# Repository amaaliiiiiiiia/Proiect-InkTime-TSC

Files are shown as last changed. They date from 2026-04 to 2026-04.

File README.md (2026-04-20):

# Proiect-InkTime-TSC
### Diagrama Bloc
Diagrama_bloc

## Tabel BOM (Bill of Materials)

| Componenta | Referinta | Link | Datasheet |
| :--- | :---: | :--- | :--- |
| **nRF52840-QFAA-F-R7** | `U1` | [JLC Parts](https://jlcpcb.com/partdetail/NordicSemicon-NRF52840_QFAA_FR7/C3606653) | [Datasheet](https://octopart.com/datasheet/nordic-semiconductor/NRF52840-QFAA-F-R7) |
| **MAX17048G+T10** | `U3` | [JLC Parts](https://jlcpcb.com/partdetail/2777647-MAX17048GT10/C2682616) | [Datasheet](https://www.analog.com/media/en/technical-documentation/data-sheets/MAX17048-MAX17049.pdf) |
| **BQ25180YBGR** | `IC1` | [JLC Parts](https://jlcpcb.com/partdetail/TexasInstruments-BQ25180YBGR/C3682423) | [Datasheet](https://www.alldatasheet.com/datasheet-pdf/view/1359210/TI/BQ25180YBGR.html) |
| **RT6160AWSC** | `IC2` | [JLC Parts](https://jlcpcb.com/partdetail/RichtekTech-RT6160AWSC/C7065276) | [Datasheet](https://www.alldatasheet.com/datasheet-pdf/view/1709403/RICHTEK/RT6160AWSC.html) |
| **BMA423** | `IC3` | [JLC Parts](https://jlcpcb.com/partdetail/BoschSensortec-BMA423/C189517) | [Datasheet](https://watchy.sqfmi.com/assets/files/BST-BMA423-DS000-1509600-950150f51058597a6234dd3eaafbb1f0.pdf) |
| **DRV2605YZFR** | `IC4` | [JLC Parts](https://jlcpcb.com/partdetail/TexasInstruments-DRV2605YZFR/C81079) | [Datasheet](https://www.ti.com/lit/ds/symlink/drv2605.pdf) |
| **2450AT18B100E** | `ANT1` | [JLC Parts](https://jlcpcb.com/partdetail/JohansonDielectrics-2450AT18B100E/C2917717) | [Datasheet](https://www.johansontechnology.com/datasheets/2450AT18B100/2450AT18B100.pdf) |
| **NX2016SA-32MHZ** | `X1` | [JLC Parts](https://jlcpcb.com/partdetail/NDK-NX2016SA_32MHZ_EXS00ACS06654/C5441424) | [Datasheet](https://mm.digikey.com/Volume0/opasdata/d220001/medias/docus/6749/CS11213-32M.pdf) |
| **ABS07-32.768KHZ** | `X2` | [JLC Parts](https://jlcpcb.com/partdetail/AbraconLLC-ABS07_32_768KHZT/C130253) | [Datasheet](https://abracon.com/Resonators/ABS07.pdf) |
| **ATFC-0201-1N0-B-T** | `L1, L2, L3` | [JLC Parts](https://jlcpcb.com/partdetail/AbraconLLC-ATFC_0201_1N0BT/C2042148) | [Datasheet](https://www.alldatasheet.com/datasheet-pdf/view/244743/ABRACON/ATFC-0201-1N0-BT.html) |
| **744043680** | `L5` | [JLC Parts](https://jlcpcb.com/partdetail/WurthElektronik-744043680/C2045671) | [Datasheet](https://www.we-online.com/catalog/datasheet/744043680.pdf) |
| **MLP2016SR47MT0S1** | `L7` | [JLC Parts](https://jlcpcb.com/parts/componentSearch?searchTxt=MLP2016SR47MT0S1) | [Datasheet](https://product.tdk.com/en/system/files/dam/doc/product/inductor/inductor/smd/catalog/inductor_commercial_power_mlp2016_en.pdf) |
| **DMG2305UX-7** | `Q1` | [JLC Parts](https://jlcpcb.com/partdetail/DiodesIncorporated-DMG2305UX7/C150470) | [Datasheet](https://www.mouser.com/datasheet/2/115/DMG2305UX-266242.pdf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) |
| **SI1308EDL-T1-GE3** | `Q3` | [JLC Parts](https://jlcpcb.com/partdetail/VishayIntertech-SI1308EDL_T1GE3/C469327) | [Datasheet](https://www.vishay.com/docs/63399/si1308edl.pdf) |
| **MBR0530** | `D2, D4, D5` | [JLC Parts](https://jlcpcb.com/partdetail/78464-MBR0530/C77336) | [Datasheet](https://www.onsemi.com/pdf/datasheet/mbr0530t1-d.pdf) |
| **USBLC6-2SC6Y** | `D3` | [JLC Parts](https://jlcpcb.com/partdetail/STMicroelectronics-USBLC62SC6Y/C2969755) | [Datasheet](https://www.st.com/resource/en/datasheet/usblc6-2.pdf) |
| **503480-2400** | `J1` | [JLC Parts](https://jlcpcb.com/partdetail/MOLEX-5034802400/C122434) | [Datasheet](https://www.molex.com/pdm_docs/sd/5034802400_sd.pdf) |
| **KH-TYPE-C-16P** | `J4` | [SnapEda](https://www.snapeda.com/parts/KH-TYPE-C-16P/Kinghelm/view-part/) | [Datasheet](https://www.snapeda.com/parts/KH-TYPE-C-16P/kinghelm/datasheet/) |
| **EVP-AKE31A** | `SW_ENT, SW_UP, SW_DN` | [JLC Parts](https://jlcpcb.com/parts/componentSearch?searchTxt=EVP-AKE31A) | [Datasheet](https://www.rxelectronics.fr/datasheet/19/evp-ake31a.pdf) |
| **02016D105KAT4A** | `0201 Capacitors` | [JLC Parts](http://jlcpcb.com/partdetail/-02016D105KAT2A/C5853878) | [Datasheet](https://datasheets.kyocera-avx.com/cx5r-KGM.pdf) |
| **0402B472K500NT** | `0402 Capacitors` | [JLC Parts](https://jlcpcb.com/partdetail/1890-0402B472K500NT/C1538) | [Datasheet](https://www.lcsc.com/datasheet/C1538.pdf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) |
| **0603N101Z160PHT** | `0603 Capacitors` | [JLC Parts](https://jlcpcb.com/partdetail/1943-CL10B104KB8NNNC/C1591) | [Datasheet](https://static.chipdip.ru/lib/970/DOC041970475.pdf) |
| **CPF0201D7K68C1** | `0201 Resistors` | [JLC Parts](https://jlcpcb.com/partdetail/TEConnectivity-CPF0201D10KC1/C4187156) | [Datasheet](https://www.snapeda.com/parts/CPF0201D4K75E1/TE%20Connectivity/datasheet/) |

## Functionalitatea Hardware
#### MCU
- Componenta: Nordic Semiconductor nRF52840
- Specificatii: Nucleu ARM Cortex-M4 cu FPU la 64 MHz, 1MB Flash si 256KB RAM
- Este responsabil de sincronizarea datelor, interpretarea miscarii ceasului, optimizarea consumului de energie si redarea informatiilor pe display

#### Display E-Paper
- Conectat prin interfata SPI
- Este un afisaj bi-stabil, iar odata ce imaginea este formata de pixeli, ramane pe ecran fara sa necesite alimentare

#### Hapic Driver
- Conectat prin I2C
- Folosit pentru notificari, alarme, prin intermediul unui motor de vibratii de tip ERM

#### BMA423
- Conectat prin I2C
- Folosit pentru numararea pasilor si pentru detectarea miscarii mainii (tilt-to-wake)

#### Fuel Gauge (MAX17048)
- Conectat prin I2C
- Monitorizeaza tensiunea bateriei si ofera informatii despre starea de incarcare
- Nu are nevoie de rezistenta de sens, deci economisseste spatiu pe PCB

#### Sursa de energie
- Utilizarea unui LiPo Charger reincarcabil de 3.7V
- Asigura o autonomie de lunga durata datorita componentelor low-power folosite

#### Managementul Alimentarii
- BQ25180 gestioneaza incarcarea bateriei prin USB-C si ofera protectie la supra-tensiune si control termic
- Convertorul RT6160 asigura o tensiune constanta de 3.3V necesara componentelor
- Dioda USBLC6-2SC6Y protejeaza liniile de date USB impotriva descarcarilor electrostatice

## Pinii nRF52840
### Tabel Alocare Pini nRF52840

| Pin | Semnal / Functie | Explicatie |
| :--- | :--- | :--- |
| **P0.00 / P0.01** | XL1/XL2 | Conexiune pentru cristalul RTC de 32.768kHz, necesar pentru low-power timekeeping |
| **P0.02** | `SCK` | Clock pentru magistrala SPI, dedicat comunicatiei cu display-ul E-Paper |
| **P0.03** | `MOSI` | Linia de date Master Out Slave In pentru transferul imaginii catre display |
| **P0.05** | `EPD_CS` | Chip Select pentru activarea display-ului pe magistrala SPI |
| **P0.06** | `SDA` | Linia de date pentru magistrala I2C (partajata de BMA423, BQ25180, MAX17048) |
| **P0.07** | `SCL` | Linia de ceas pentru magistrala I2C |
| **P0.08** | `IMU_INT1` | Intrerupere primara de la BMA423 |
| **P0.10** | `ALERT` | Semnal de alerta |
| **P0.11** | `PMIC_INT` | Intrerupere de la IC-ul de management al bateriei |
| **P0.12** | `HAPTIC_EN` | Activeaza driverul DRV2605 |
| **P0.13** | `SW_UP` | Buton UP |
| **P0.14** | `SW_DN` | Buton DOWN |
| **P0.15** | `EPD_DC` | Data / Command select pentru display |
| **P0.16** | `EPD_RST` | Reset hardware pentru dispay |
| **P0.17** | `EPD_BUSY` | Statusul ecranului |
| **P0.18** | `RESET` | Reset general, legat la TC2030. |
| **P1.00** | `SW_ENT` | Buton ENTER |
| **P1.08** | `IMU_INT2` | Intrerupere secundara de la BMA423 |

## Justificarea Erorilor
Am acceptat cele 13 erori de tip Copper Clearance de pe componenta IC2 deoarece am prioritizat rutarea corecta a traseelor de tip 3V3, folosind 0.3mm.

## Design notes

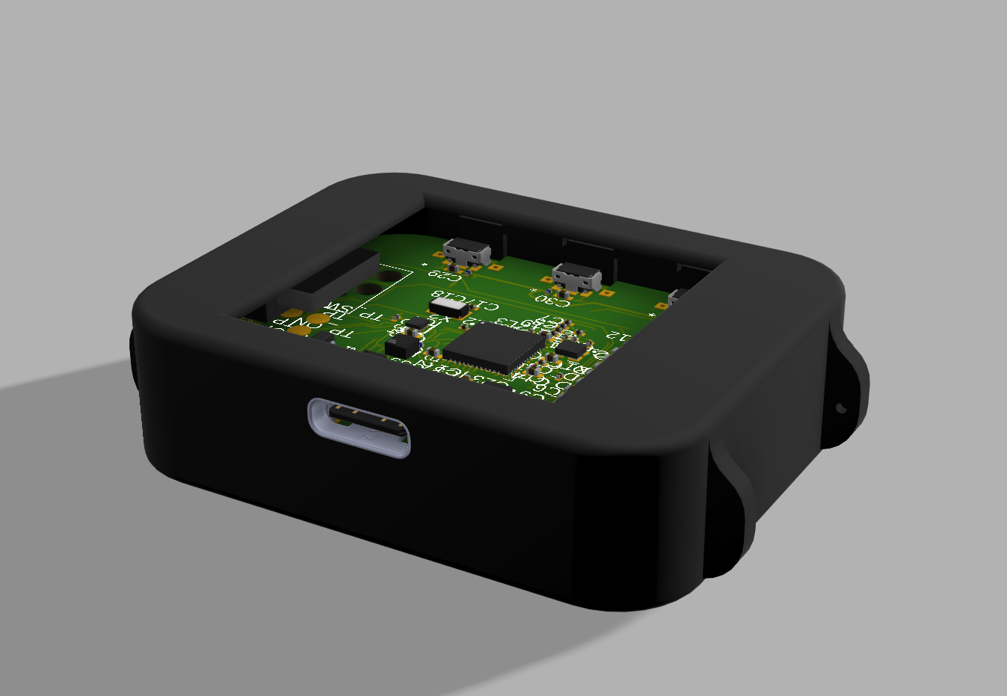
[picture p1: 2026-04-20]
Images/carcasa+pcb.jpeg

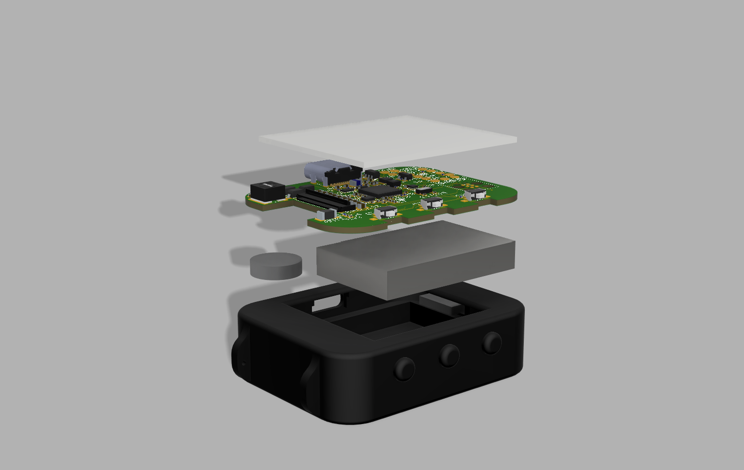
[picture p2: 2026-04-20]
Images/exploded_view2.jpeg

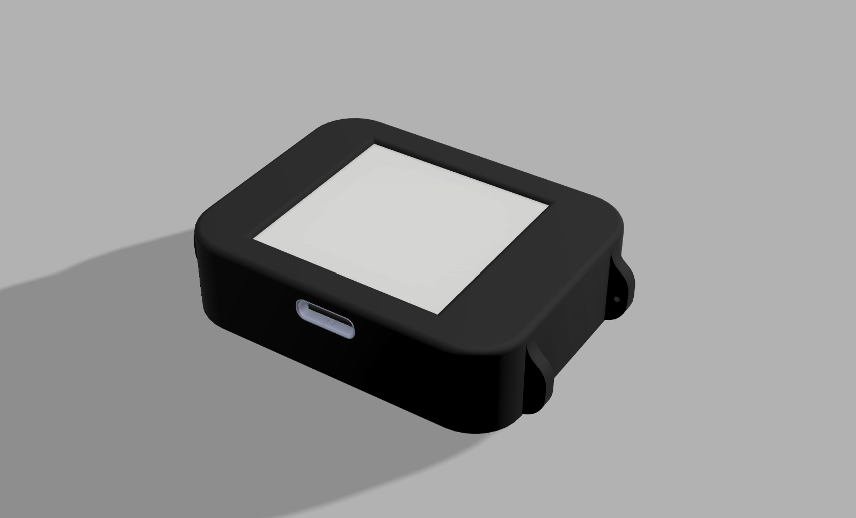
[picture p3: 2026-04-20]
Images/dispozitiv_final1.jpeg

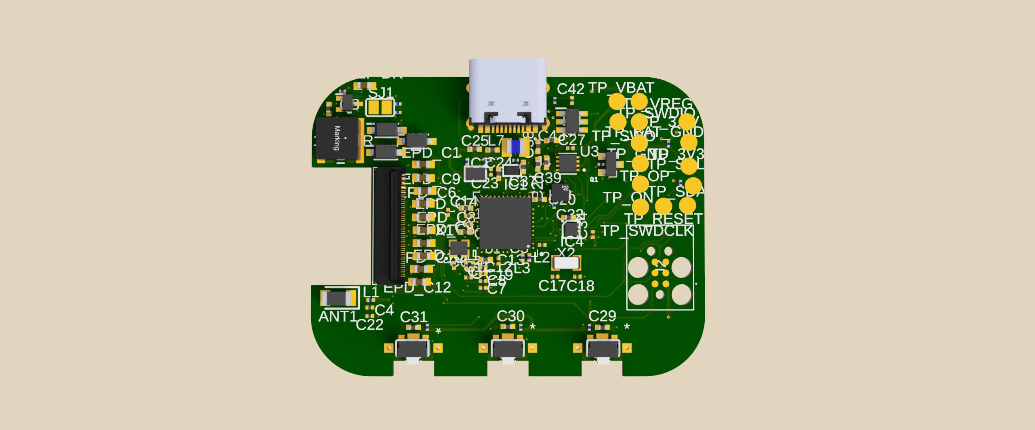
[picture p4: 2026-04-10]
Images/pcb_3d_fata.JPEG

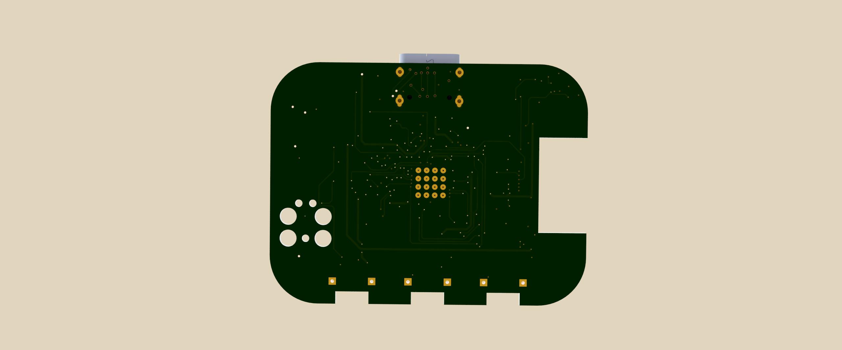
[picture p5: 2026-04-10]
Images/pcb_3d_spate.JPEG

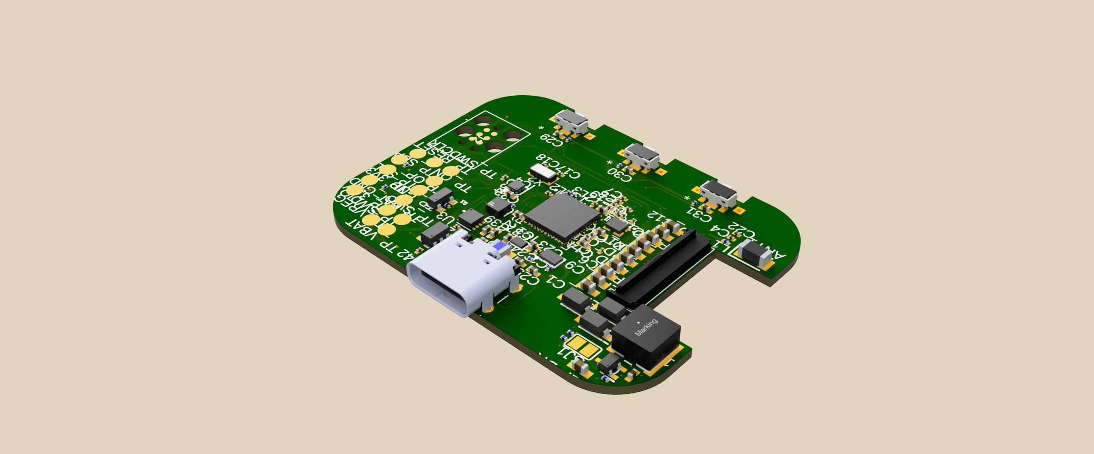
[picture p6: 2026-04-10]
Images/pcb_3d.JPEG

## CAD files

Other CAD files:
Mechanical/InkTime_pcb3d.f3d
Mechanical/Produs Final 3D.f3z

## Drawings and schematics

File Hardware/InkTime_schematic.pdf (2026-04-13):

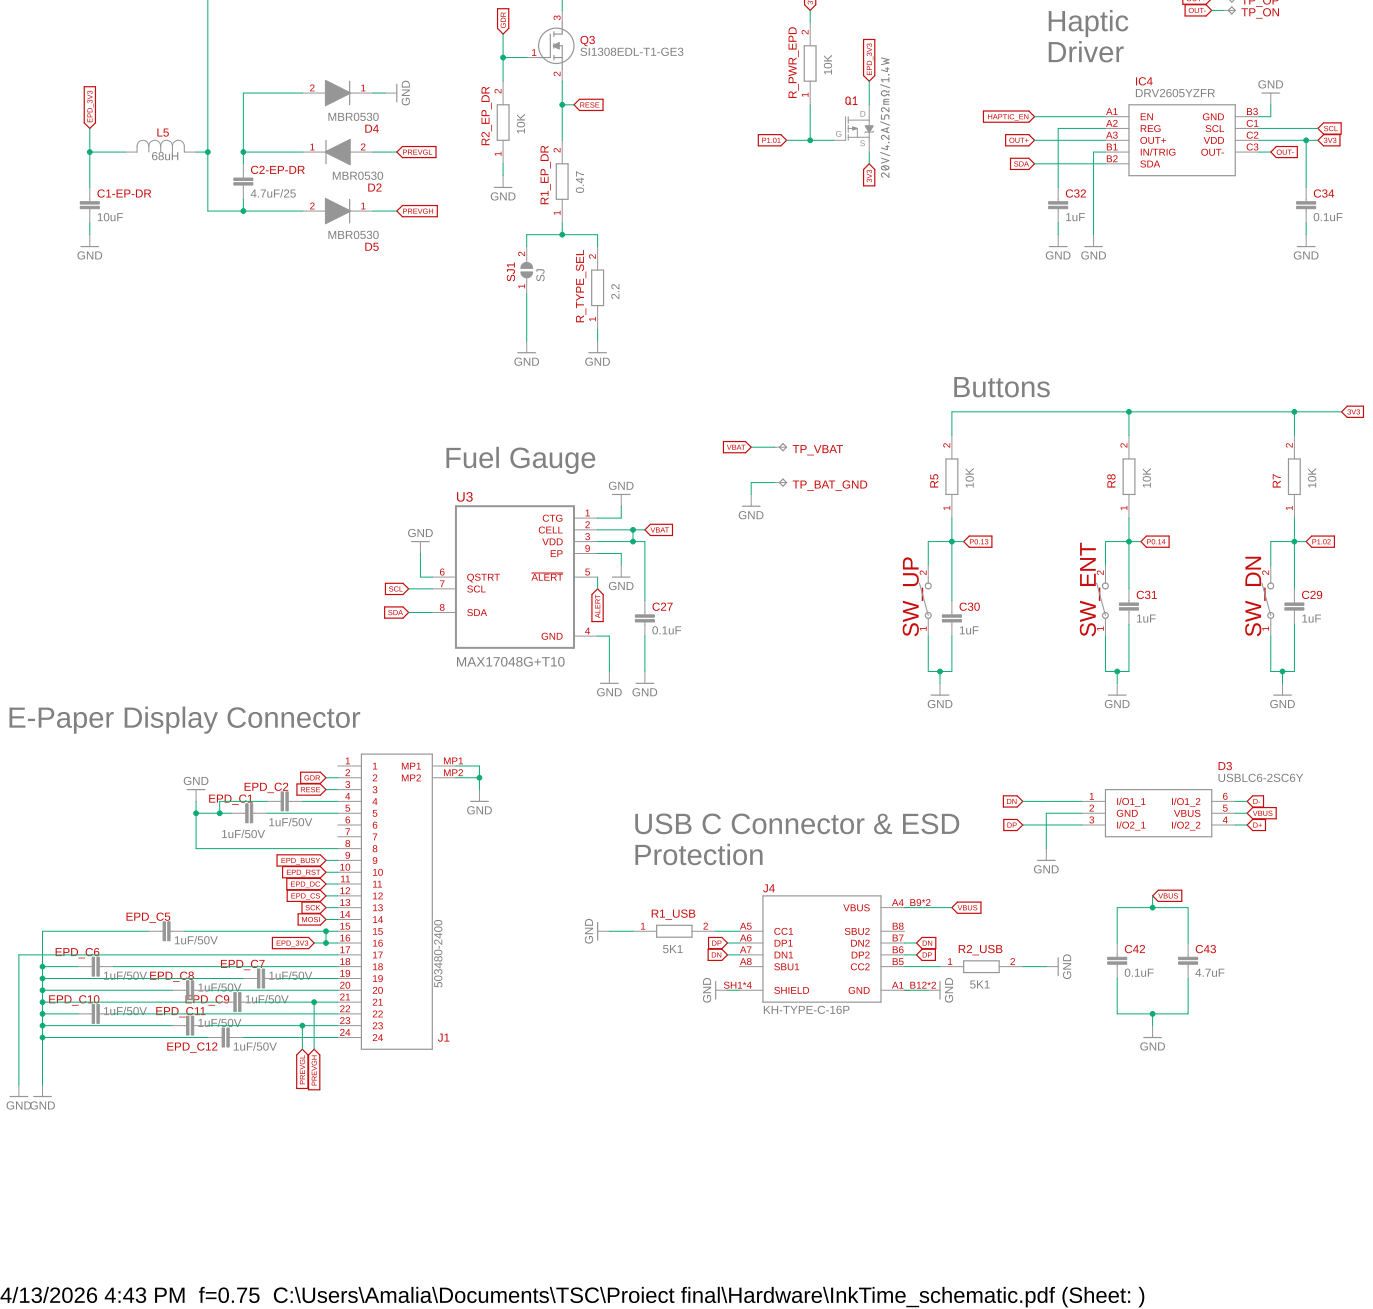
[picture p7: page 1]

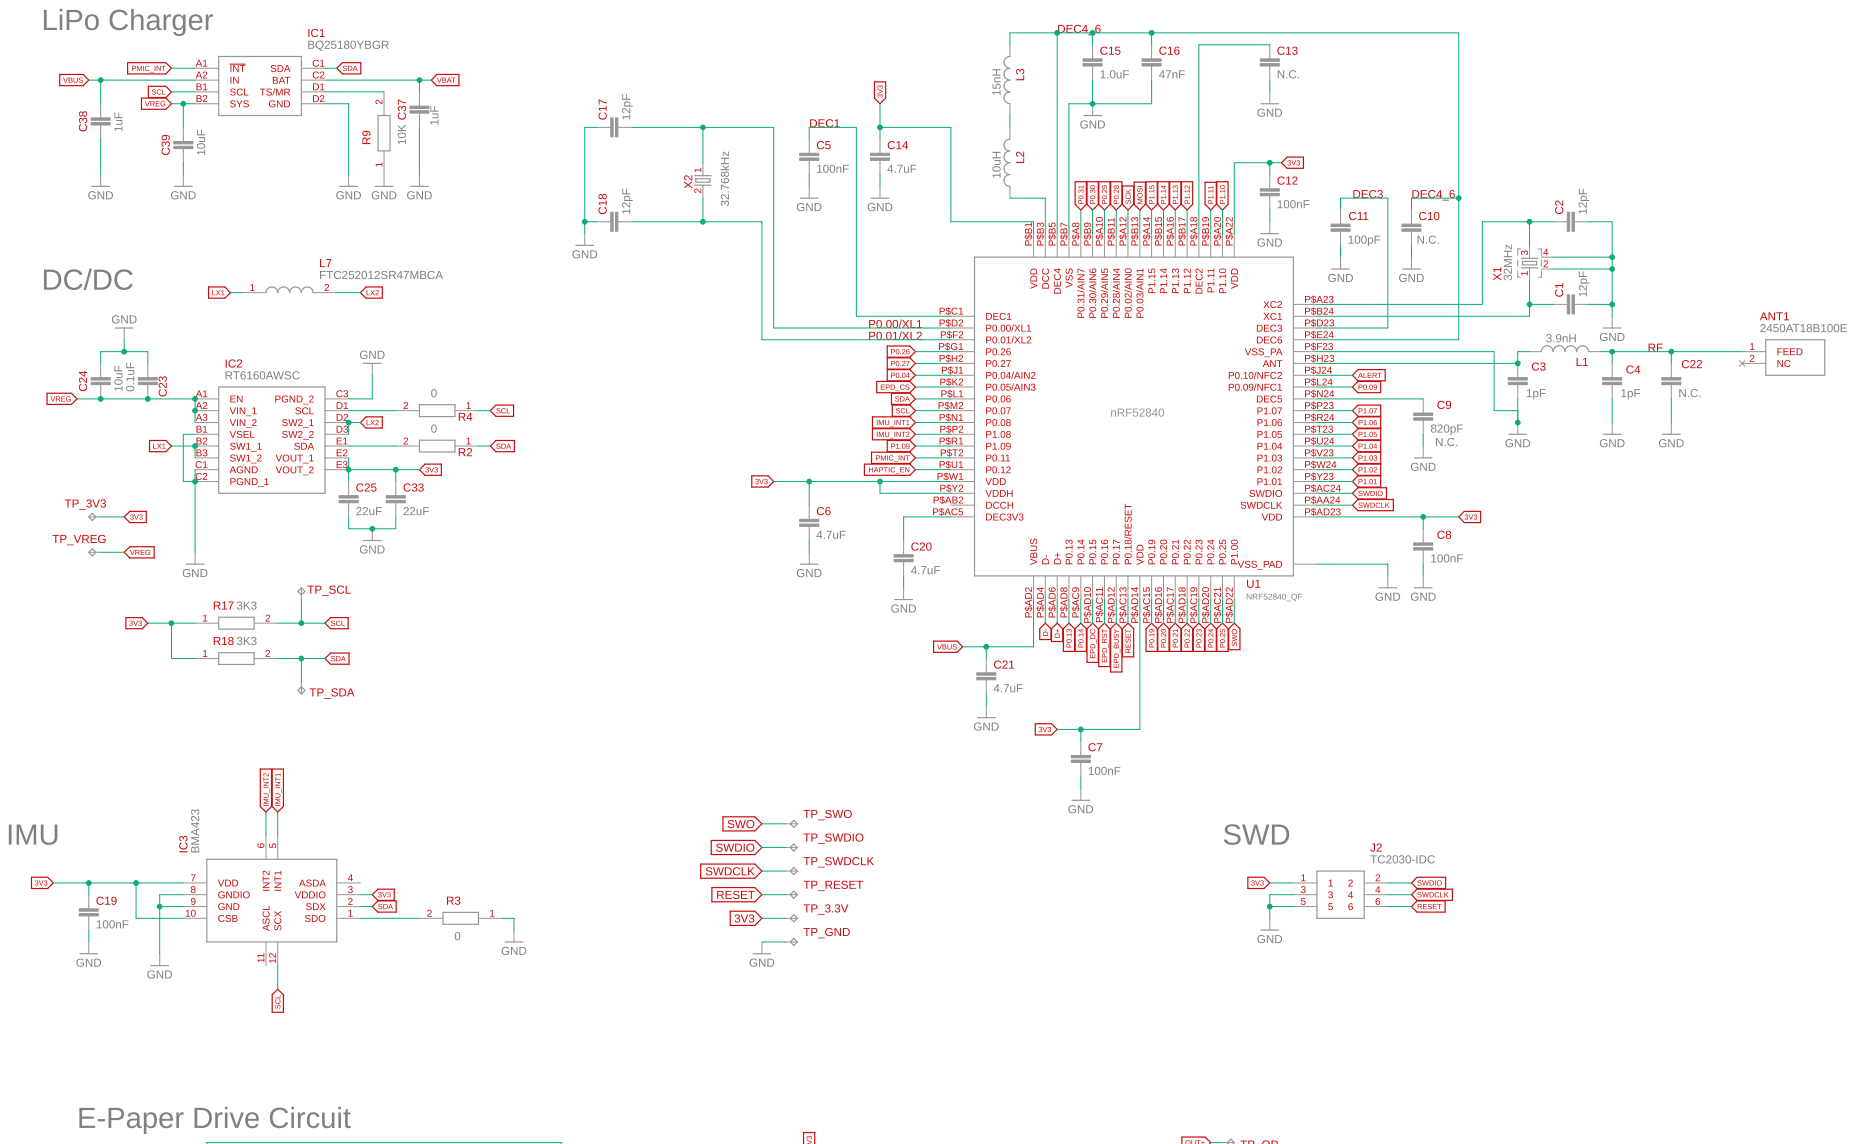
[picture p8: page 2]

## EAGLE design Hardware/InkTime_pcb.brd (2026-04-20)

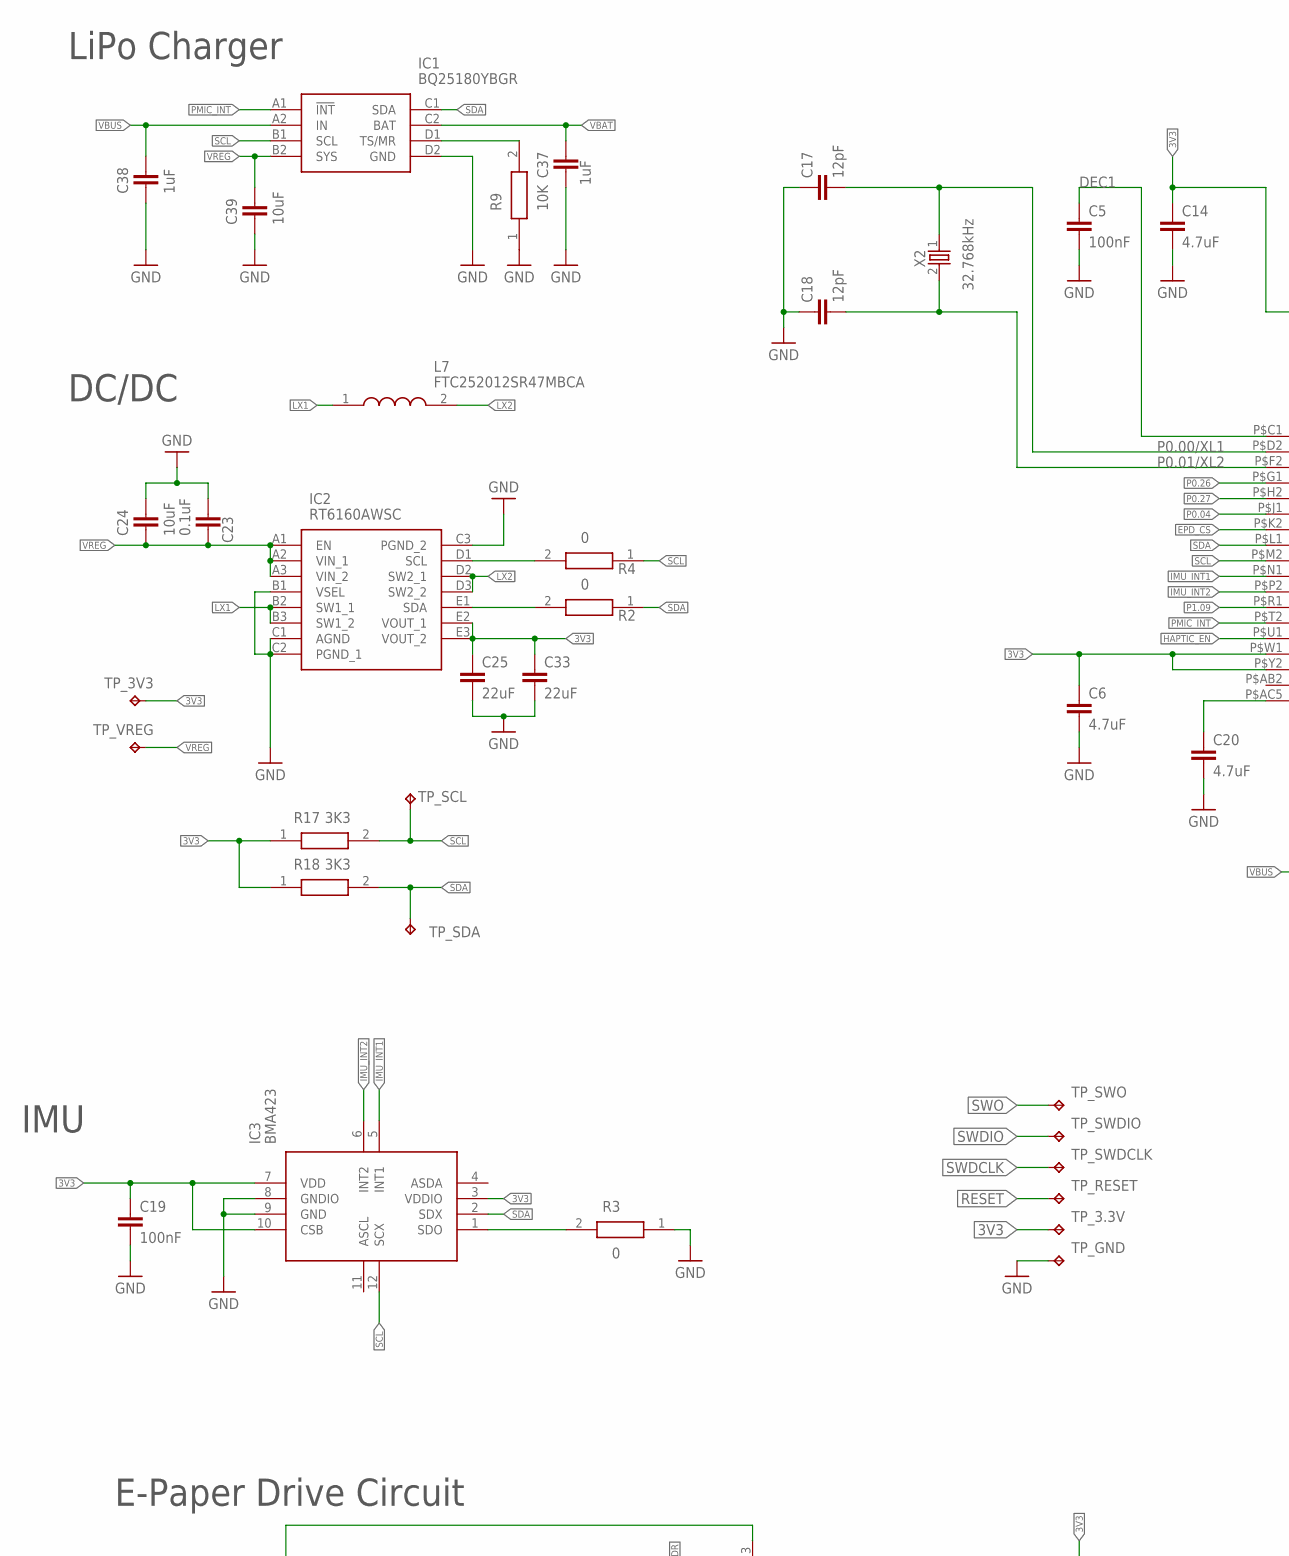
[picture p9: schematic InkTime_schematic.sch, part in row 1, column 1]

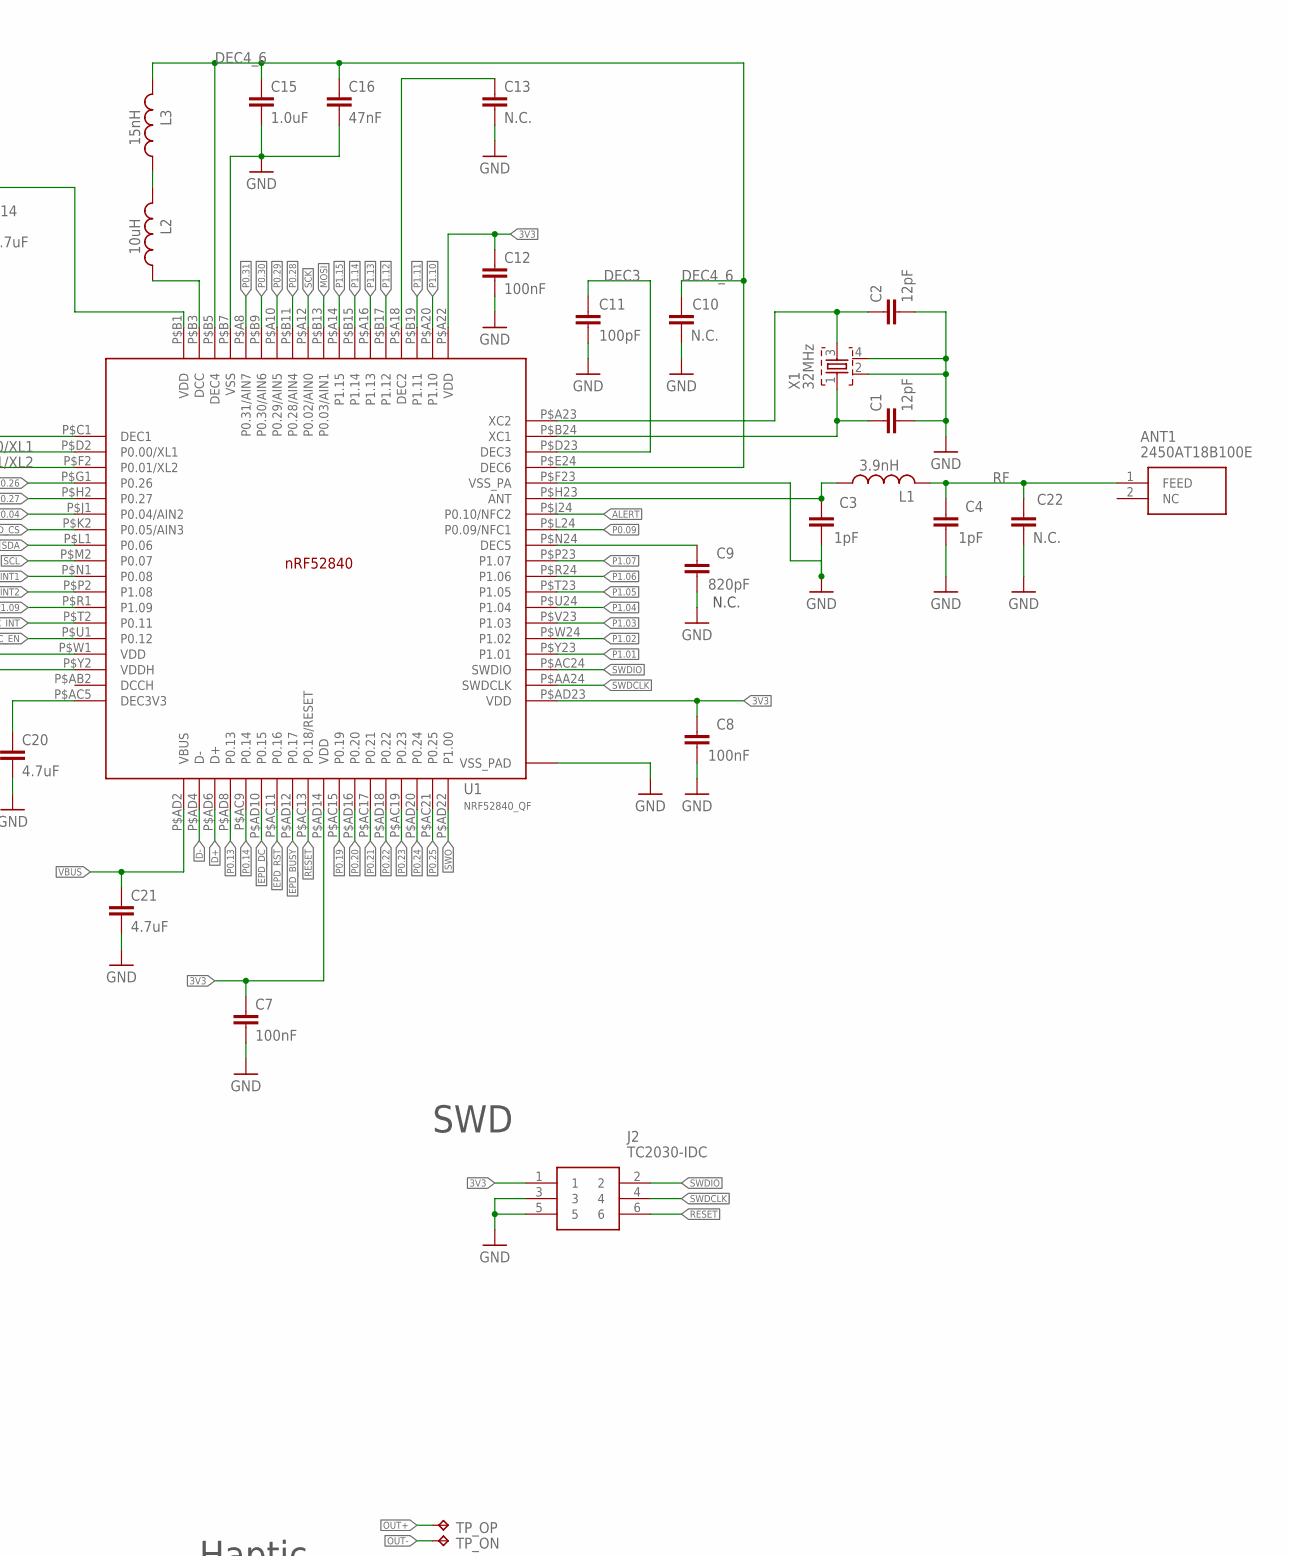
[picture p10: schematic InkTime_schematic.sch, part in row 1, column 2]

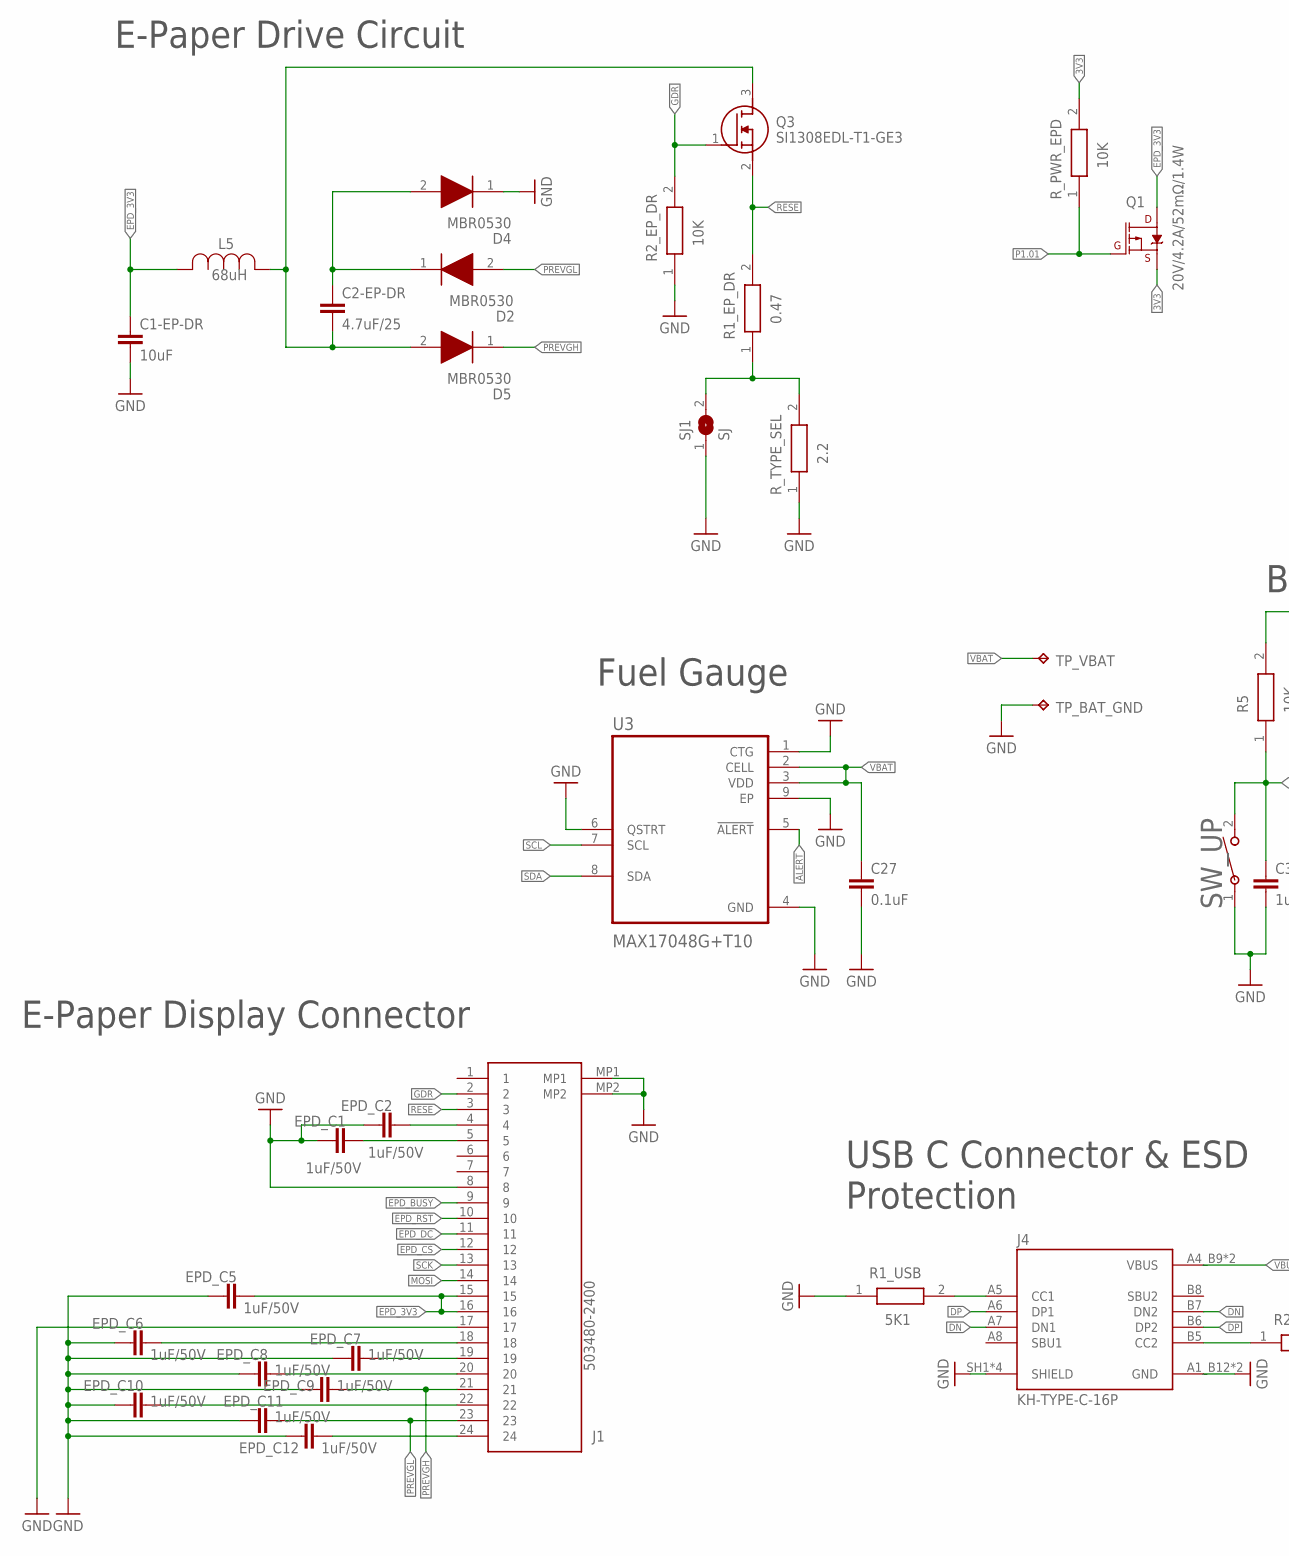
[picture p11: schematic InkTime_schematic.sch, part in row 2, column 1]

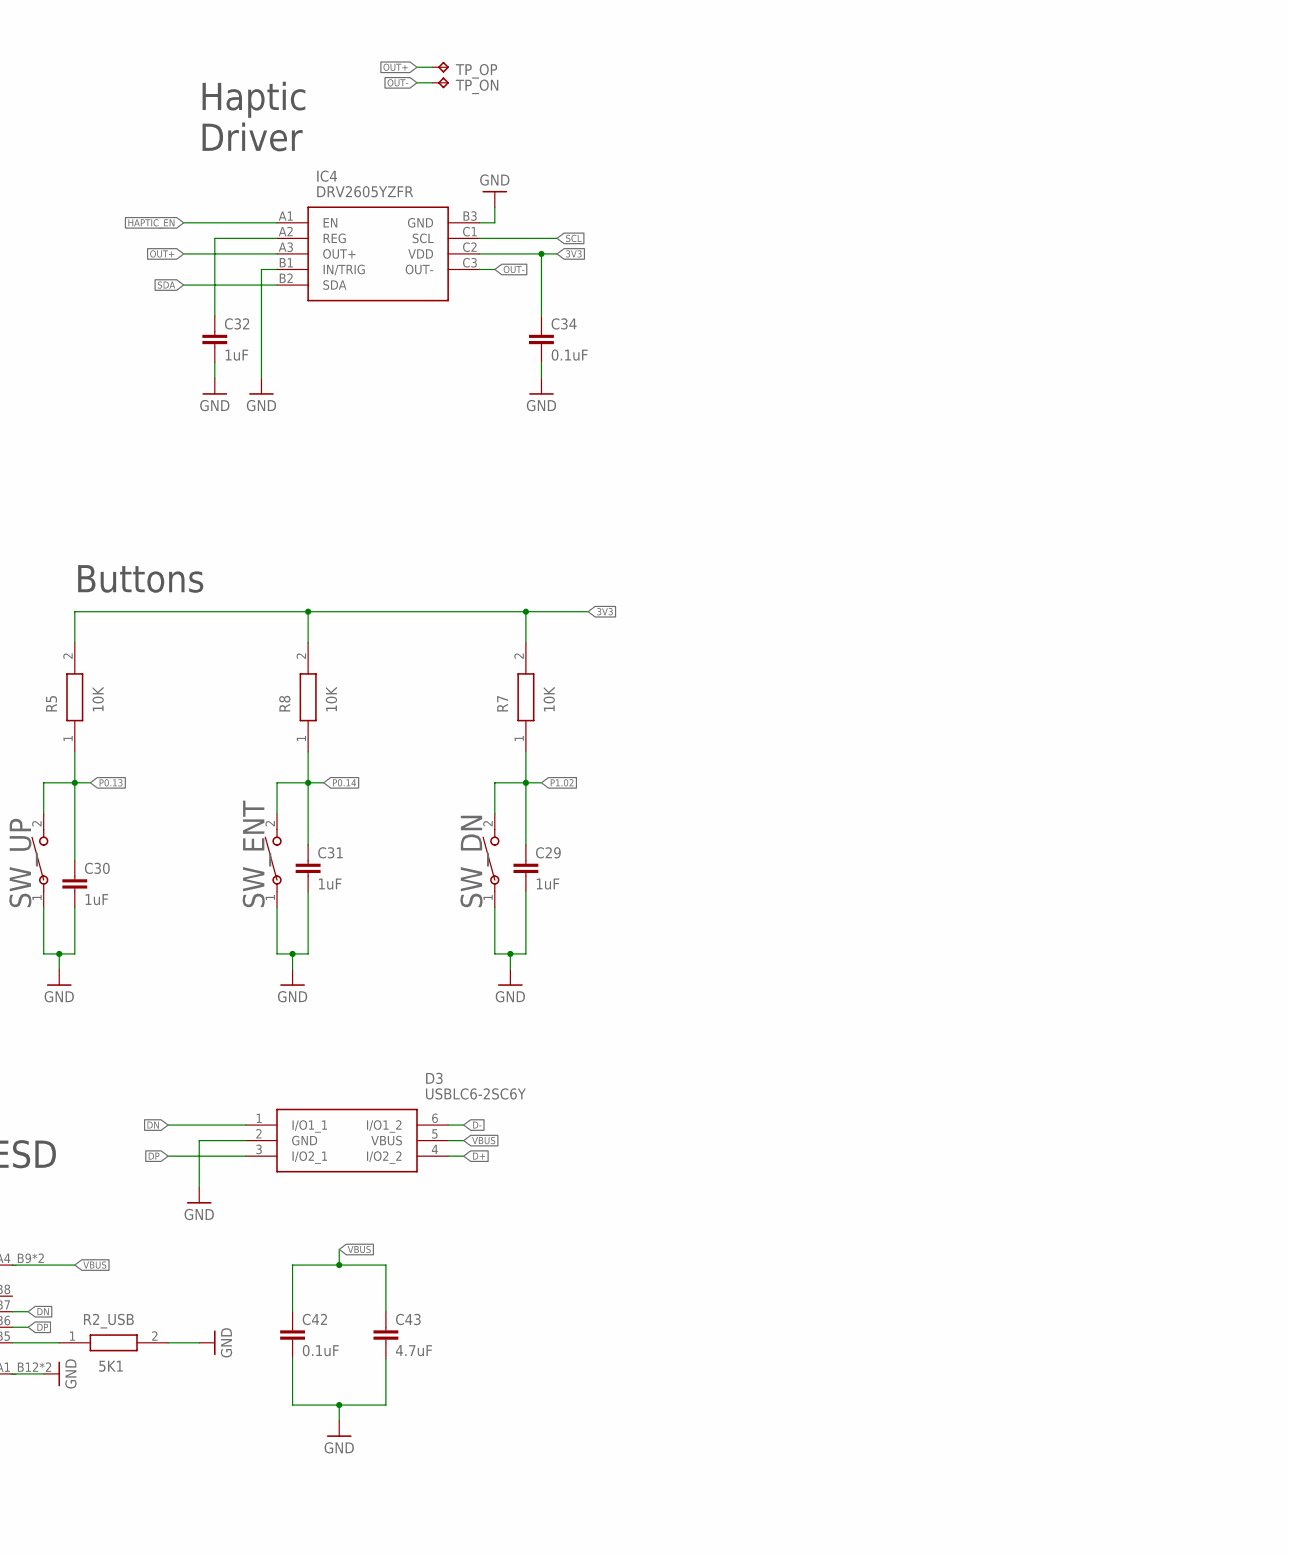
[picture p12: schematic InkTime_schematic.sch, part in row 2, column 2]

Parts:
ANT1: 2450AT18B100E; 2450AT18B100E_ANTC3216X140N
C1, C2, C17, C18: 12pF; NORDIC_NRF_3_RESC0201_N
C1-EP-DR, C24, C39: 10uF; NORDIC_NRF_3_RESC0402_N
C2-EP-DR: 4.7uF/25; NORDIC_NRF_3_RESC0603_N
C3, C4: 1pF; NORDIC_NRF_3_RESC0201_N
C5, C7, C8, C12, C19: 100nF; NORDIC_NRF_3_RESC0201_N
C6, C14, C20, C21, C43: 4.7uF; NORDIC_NRF_3_RESC0402_N
C9: 820pF; NORDIC_NRF_3_RESC0201_N
C10, C13, C22: N.C.; NORDIC_NRF_3_RESC0201_N
C11: 100pF; NORDIC_NRF_3_RESC0201_N
C15: 1.0uF; NORDIC_NRF_3_RESC0402_N
C16: 47nF; NORDIC_NRF_3_RESC0201_N
C23, C27, C34, C42: 0.1uF; NORDIC_NRF_3_RESC0201_N
C25, C33: 22uF; NORDIC_NRF_3_RESC0402_N
C29, C30, C31, C32, C37, C38: 1uF; NORDIC_NRF_3_RESC0402_N
D2, D4, D5: MBR0530; ESP32_C6_LIBRARY_5_SOD3716X135N
D3: USBLC6-2SC6Y; ESP32_C6_LIBRARY_3_SOT95P280X145-6N
EPD_C1, EPD_C2, EPD_C5, EPD_C6, EPD_C7, EPD_C8, EPD_C9, EPD_C10, EPD_C11, EPD_C12: 1uF/50V; NORDIC_NRF_3_RESC0603_N
IC1: BQ25180YBGR; BQ25180YBGR_BGA8C40P2X4_100X155X50
IC2: RT6160AWSC; RT6160AWSC_BGA15C40P3X5_140X230X60
IC3: BMA423; BMA423_BMA423
IC4: DRV2605YZFR; DRV2605YZFR_BGA9C50P3X3_144X144X62
J1: 503480-2400; 503480-2400_5034802400
J2: TC2030-IDC; TC2030-IDC_TC2030IDC
J4: KH-TYPE-C-16P; KH-TYPE-C-16P_KINGHELM_KH-TYPE-C-16P
L1: 3.9nH; NORDIC_NRF_2_RESC0201_N
L2: 10uH; NORDIC_NRF_2_RESC0201_N
L3: 15nH; NORDIC_NRF_2_RESC0201_N
L5: 68uH; ESP32_C6_LIBRARY_2_IND_4828-WE-TPC_WRE
L7: FTC252012SR47MBCA; MLP2016SR47MT0S1_INDC2016X100N
Q1: 20V/4.2A/52mΩ/1.4W; ESP32_C6_LIBRARY_4_ESP32_C6_LIBRARY_4_ESP32_C6_LIBRARY_4_ES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
Q3: SI1308EDL-T1-GE3; ESP32_C6_LIBRARY_6_SOT65P210X110-3N
R1_EP_DR: 0.47; ERA-1AEB3401C_0201
R1_USB, R2_USB: 5K1; CPF0201D7K68C1_0201
R2, R4: 0; CPF0201D7K68C1_0201
R2_EP_DR, R5, R7, R8: 10K; ERA-1AEB3401C_0201
R3: 0; ERA-1AEB3401C_0201
R9: 10K; CPF0201D7K68C1_0201
R17, R18: 3K3; CPF0201D7K68C1_0201
R_PWR_EPD: 10K; CPF0201D7K68C1_0201
R_TYPE_SEL: 2.2; ERA-1AEB3401C_0201
SJ1: SJ; ESP32_C6_LIBRARY_7_JUMPER_SJ
SW_DN: SW_DN; 2025-10-22_07-23-44_LIBRARY_SW_EVP-AKE31A_PAN
SW_ENT: SW_ENT; 2025-10-22_07-23-44_LIBRARY_SW_EVP-AKE31A_PAN
SW_UP: SW_UP; 2025-10-22_07-23-44_LIBRARY_SW_EVP-AKE31A_PAN
TP_3.3V, TP_3V3: HECTOR_WATCH_1_TPTP20R; HECTOR_WATCH_1_TP20R
TP_BAT_GND: HECTOR_WATCH_1_TPTP20R; HECTOR_WATCH_1_TP20R
TP_GND: HECTOR_WATCH_1_TPTP20R; HECTOR_WATCH_1_TP20R
TP_ON: HECTOR_WATCH_1_TPTP20R; HECTOR_WATCH_1_TP20R
TP_OP: HECTOR_WATCH_1_TPTP20R; HECTOR_WATCH_1_TP20R
TP_RESET: HECTOR_WATCH_1_TPTP20R; HECTOR_WATCH_1_TP20R
TP_SCL: HECTOR_WATCH_1_TPTP20R; HECTOR_WATCH_1_TP20R
TP_SDA: HECTOR_WATCH_1_TPTP20R; HECTOR_WATCH_1_TP20R
TP_SWDCLK: HECTOR_WATCH_1_TPTP20R; HECTOR_WATCH_1_TP20R
TP_SWDIO: HECTOR_WATCH_1_TPTP20R; HECTOR_WATCH_1_TP20R
TP_SWO: HECTOR_WATCH_1_TPTP20R; HECTOR_WATCH_1_TP20R
TP_VBAT: HECTOR_WATCH_1_TPTP20R; HECTOR_WATCH_1_TP20R
TP_VREG: HECTOR_WATCH_1_TPTP20R; HECTOR_WATCH_1_TP20R
U1: NRF52840_QF; NORDIC_NRF_4_AQFN50P700X700X85_HS-74N
U3: MAX17048G+T10; ESP32_C6_LIBRARY_SON50P200X200X80-9N
X1: 32MHz; NORDIC_NRF_BT-XTAL_2016_N
X2: 32.768kHz; NORDIC_NRF_1_XTAL_3215_N

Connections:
3V3: C6.1, C7.1, C8.2, C12.1, C14.1, C19.1, C25.1, C33.1, C34.1, IC2.E2 (VOUT_1), IC2.E3 (VOUT_2), IC3.3 (VDDIO), IC3.7 (VDD), IC3.10 (CSB), IC4.C2 (VDD), J2.1, Q1.2 (S), R5.2, R7.2, R8.2, R17.1, R18.1, R_PWR_EPD.2, TP_3.3V.TP, TP_3V3.TP, U1.P$A22 (VDD), U1.P$AD14 (VDD), U1.P$AD23 (VDD), U1.P$B1 (VDD), U1.P$W1 (VDD), U1.P$Y2 (VDDH)
ALERT: U1.P$J24 (P0.10/NFC2), U3.5 (!ALERT)
D+: D3.4 (I/O2_2), U1.P$AD6 (D+)
D-: D3.6 (I/O1_2), U1.P$AD4 (D-)
DEC1: C5.1, U1.P$C1 (DEC1)
DEC3: C11.2, U1.P$D23 (DEC3)
DEC4_6: C10.2, C15.1, C16.1, L3.2, U1.P$B5 (DEC4), U1.P$E24 (DEC6)
DN: D3.1 (I/O1_1), J4.A7 (DN1), J4.B7 (DN2)
DP: D3.3 (I/O2_1), J4.A6 (DP1), J4.B6 (DP2)
EPD_3V3: C1-EP-DR.1, EPD_C5.2, J1.15, J1.16, L5.2, Q1.3 (D)
EPD_BUSY: J1.9, U1.P$AD12 (P0.17)
EPD_CS: J1.12, U1.P$K2 (P0.05/AIN3)
EPD_DC: J1.11, U1.P$AD10 (P0.15)
EPD_RST: J1.10, U1.P$AC11 (P0.16)
GDR: J1.2, Q3.1 (G), R2_EP_DR.2
GND: C1.2, C1-EP-DR.2, C2.2, C3.1, C4.1, C5.2, C6.2, C7.2, C8.1, C9.1, C10.1, C11.1, C12.2, C13.2, C14.2, C15.2, C16.2, C17.1, C18.1, C19.2, C20.2, C21.2, C22.2, C23.1, C24.1, C25.2, C27.2, C29.2, C30.2, C31.2, C32.2, C33.2, C34.2, C37.2, C38.2, C39.2, C42.2, C43.2, D3.2 (GND), D4.1 (K), EPD_C1.1, EPD_C2.1, EPD_C5.1, EPD_C6.1, EPD_C7.1, EPD_C8.1, EPD_C9.1, EPD_C10.1, EPD_C11.1, EPD_C12.1, IC1.D2 (GND), IC2.B1 (VSEL), IC2.C1 (AGND), IC2.C2 (PGND_1), IC2.C3 (PGND_2), IC3.8 (GNDIO), IC3.9 (GND), IC4.B1 (IN/TRIG), IC4.B3 (GND), J1.8, J1.17, J1.MP1, J1.MP2, J2.3, J2.5, J4.A1_B12 (GND), J4.A12_B1 (GND), J4.SH1 (SHIELD), J4.SH2 (SHIELD), J4.SH3 (SHIELD), J4.SH4 (SHIELD), R1_USB.1, R2_EP_DR.1, R2_USB.2, R3.1, R9.1, R_TYPE_SEL.1, SJ1.1, SW_DN.1, SW_ENT.1, SW_UP.1, TP_BAT_GND.TP, TP_GND.TP, U1.P$74 (VSS_PAD), U1.P$75 (VSS_PAD), U1.P$76 (VSS_PAD), U1.P$77 (VSS_PAD), U1.P$78 (VSS_PAD), U1.P$79 (VSS_PAD), U1.P$80 (VSS_PAD), U1.P$81 (VSS_PAD), U1.P$82 (VSS_PAD), U1.P$83 (VSS_PAD), U1.P$84 (VSS_PAD), U1.P$85 (VSS_PAD), U1.P$86 (VSS_PAD), U1.P$87 (VSS_PAD), U1.P$88 (VSS_PAD), U1.P$89 (VSS_PAD), U1.P$90 (VSS_PAD), U1.P$B7 (VSS), U1.P$F23 (VSS_PA), U3.1 (CTG), U3.4 (GND), U3.6 (QSTRT), U3.9 (EP), X1.2, X1.4
HAPTIC_EN: IC4.A1 (EN), U1.P$U1 (P0.12)
IMU_INT1: IC3.5 (INT1), U1.P$N1 (P0.08)
IMU_INT2: IC3.6 (INT2), U1.P$P2 (P1.08)
LX1: IC2.B2 (SW1_1), IC2.B3 (SW1_2), L7.1
LX2: IC2.D2 (SW2_1), IC2.D3 (SW2_2), L7.2
MOSI: J1.14, U1.P$B13 (P0.03/AIN1)
unnamed: C1.1, U1.P$B24 (XC1), X1.1
unnamed: C2.1, U1.P$A23 (XC2), X1.3
unnamed: C3.2, L1.1, U1.P$H23 (ANT)
unnamed: C9.2, U1.P$N24 (DEC5)
unnamed: C13.1, U1.P$A18 (DEC2)
unnamed: IC2.D1 (SCL), R4.2
unnamed: L2.1, U1.P$B3 (DCC)
unnamed: L2.2, L3.1
unnamed: C20.1, U1.P$AC5 (DEC3V3)
unnamed: EPD_C2.2, J1.4
unnamed: IC1.D1 (TS/MR), R9.2
unnamed: IC2.E1 (SDA), R2.2
unnamed: C32.1, IC4.A2 (REG)
unnamed: R1_EP_DR.1, R_TYPE_SEL.2, SJ1.2
unnamed: IC3.1 (SDO), R3.2
unnamed: C2-EP-DR.1, D2.1 (K), D4.2 (A)
unnamed: C2-EP-DR.2, D5.2 (A), L5.1, Q3.3 (D)
unnamed: EPD_C1.2, J1.5
unnamed: J4.B5 (CC2), R2_USB.1
unnamed: J4.A5 (CC1), R1_USB.2
unnamed: EPD_C6.2, J1.18
unnamed: EPD_C7.2, J1.19
unnamed: EPD_C8.2, J1.20
unnamed: EPD_C10.2, J1.22
unnamed: EPD_C12.2, J1.24
OUT+: IC4.A3 (OUT+), TP_OP.TP
OUT-: IC4.C3 (OUT-), TP_ON.TP
P0.00/XL1: C17.2, U1.P$D2 (P0.00/XL1), X2.1
P0.01/XL2: C18.2, U1.P$F2 (P0.01/XL2), X2.2
P0.04: U1.P$J1 (P0.04/AIN2)
P0.09: U1.P$L24 (P0.09/NFC1)
P0.13: C30.1, R5.1, SW_UP.2, U1.P$AD8 (P0.13)
P0.14: C31.1, R8.1, SW_ENT.2, U1.P$AC9 (P0.14)
P0.19: U1.P$AC15 (P0.19)
P0.20: U1.P$AD16 (P0.20)
P0.21: U1.P$AC17 (P0.21)
P0.22: U1.P$AD18 (P0.22)
P0.23: U1.P$AC19 (P0.23)
P0.24: U1.P$AD20 (P0.24)
P0.25: U1.P$AC21 (P0.25)
P0.26: U1.P$G1 (P0.26)
P0.27: U1.P$H2 (P0.27)
P0.28: U1.P$B11 (P0.28/AIN4)
P0.29: U1.P$A10 (P0.29/AIN5)
P0.30: U1.P$B9 (P0.30/AIN6)
P0.31: U1.P$A8 (P0.31/AIN7)
P1.01: Q1.1 (G), R_PWR_EPD.1, U1.P$Y23 (P1.01)
P1.02: C29.1, R7.1, SW_DN.2, U1.P$W24 (P1.02)
P1.03: U1.P$V23 (P1.03)
P1.04: U1.P$U24 (P1.04)
P1.05: U1.P$T23 (P1.05)
P1.06: U1.P$R24 (P1.06)
P1.07: U1.P$P23 (P1.07)
P1.09: U1.P$R1 (P1.09)
P1.10: U1.P$A20 (P1.10)
P1.11: U1.P$B19 (P1.11)
P1.12: U1.P$B17 (P1.12)
P1.13: U1.P$A16 (P1.13)
P1.14: U1.P$B15 (P1.14)
P1.15: U1.P$A14 (P1.15)
PMIC_INT: IC1.A1 (!INT), U1.P$T2 (P0.11)
PREVGH: D5.1 (K), EPD_C9.2, J1.21
PREVGL: D2.2 (A), EPD_C11.2, J1.23
RESE: J1.3, Q3.2 (S), R1_EP_DR.2
RESET: J2.6, TP_RESET.TP, U1.P$AC13 (P0.18/RESET)
RF: ANT1.1 (FEED), C4.2, C22.1, L1.2
SCK: J1.13, U1.P$A12 (P0.02/AIN0)
SCL: IC1.B1 (SCL), IC3.12 (SCX), IC4.C1 (SCL), R4.1, R17.2, TP_SCL.TP, U1.P$M2 (P0.07), U3.7 (SCL)
SDA: IC1.C1 (SDA), IC3.2 (SDX), IC4.B2 (SDA), R2.1, R18.2, TP_SDA.TP, U1.P$L1 (P0.06), U3.8 (SDA)
SWDCLK: J2.4, TP_SWDCLK.TP, U1.P$AA24 (SWDCLK)
SWDIO: J2.2, TP_SWDIO.TP, U1.P$AC24 (SWDIO)
SWO: TP_SWO.TP, U1.P$AD22 (P1.00)
VBAT: C27.1, C37.1, IC1.C2 (BAT), TP_VBAT.TP, U3.2 (CELL), U3.3 (VDD)
VBUS: C21.1, C38.1, C42.1, C43.1, D3.5 (VBUS), IC1.A2 (IN), J4.A4_B9 (VBUS), J4.A9_B4 (VBUS), U1.P$AD2 (VBUS)
VREG: C23.2, C24.2, C39.1, IC1.B2 (SYS), IC2.A1 (EN), IC2.A2 (VIN_1), IC2.A3 (VIN_2), TP_VREG.TP

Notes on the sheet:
N.C.
LiPo Charger
DC/DC
IMU
SWD
E-Paper Drive Circuit
E-Paper Display Connector
Fuel Gauge
Haptic Driver
Buttons
USB C Connector & ESD Protection

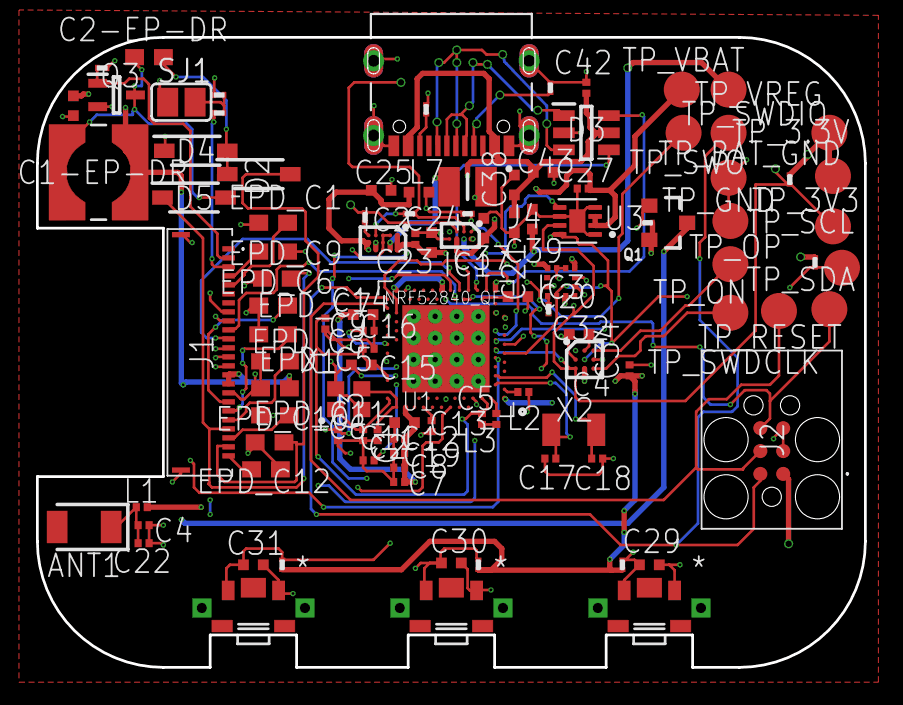
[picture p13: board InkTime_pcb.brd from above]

Board: 4 copper layers, 46.0 x 35.0 mm, 105 parts (0 on the bottom side), 70 nets.

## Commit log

2026-04-10 schematic, pcb 2d
    [InkTime_pcb.brd, InkTime_schematic.sch]
2026-04-10 pcb 3d
2026-04-10 randari pcb 3d
2026-04-10 pcb 3d .step
2026-04-13 Fisierele gerbers, .bom si .cpl
2026-04-13 schematic .pdf
2026-04-13 PCB + baterie + display + carcasa (exploded view si Fusion360)
2026-04-20 Diagrama si Tabel BOM in README
2026-04-20 Am rezolvat issue-urile din pcb 2d
    [InkTime_pcb.brd]
2026-04-20 Varianta finala
    [InkTime_pcb3d.f3d, Produs Final 3D.f3z]

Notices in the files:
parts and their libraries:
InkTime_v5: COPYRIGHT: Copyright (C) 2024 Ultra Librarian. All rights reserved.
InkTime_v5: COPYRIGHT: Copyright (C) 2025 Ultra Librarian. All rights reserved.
